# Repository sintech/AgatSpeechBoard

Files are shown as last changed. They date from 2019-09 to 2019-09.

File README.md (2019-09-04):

# Agat Speech Board

КР1803ВЖ1 (TMS5100) based speech synthesizer board for [Agat](https://en.wikipedia.org/wiki/Agat_(computer)) computer.

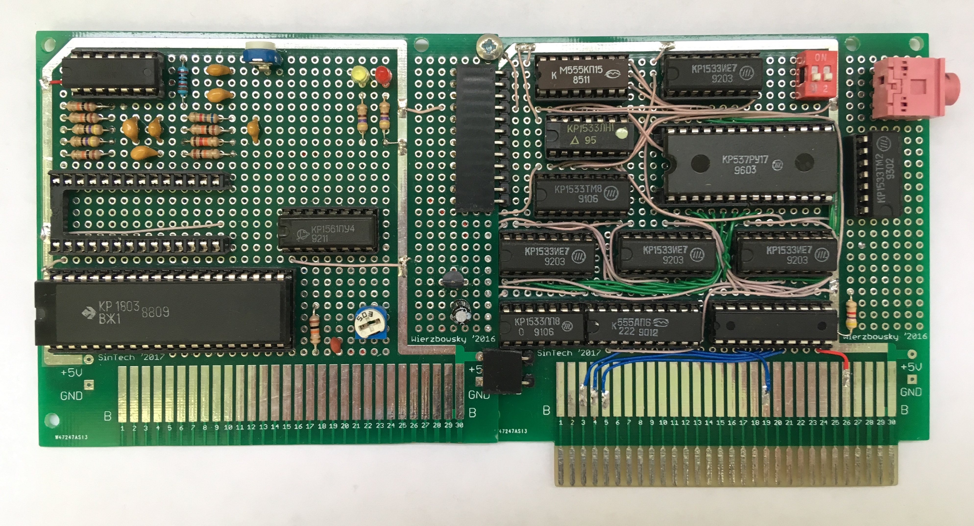
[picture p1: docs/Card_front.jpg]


Schematics was designed in KiCad EDA with a custom parts lib.
Software was created using [cc65](https://cc65.github.io/) compiler. And it works on Agat only in Apple II compatibility mode.

## Project files
- Schematics in KiCad format: [schematics/AgatSpeechBoard](schematics/AgatSpeechBoard), PNG: [Control](schematics/AgatSpeechBoard/AgatSpeechBoard_sch.png), [Analog](schematics/AgatSpeechBoard/AgatSpeechBoard_analog_sch.png)
- ATF16v8 PLD firmware: [PLD Firmware](src/ATF16V8)
- Speak program sources for Agat-9 Apple II mode: [src/speak](src/speak)
- Various datasheets for КР1803ВЖ1 and TMS5100 chips: [docs](docs)
- "Talking Dice" circuit based on TMS5100 chip: [docs/Talking Dice](docs/Talking%20Dice)

## [Chaos Constructions 2019](http://c-c.ru) public report
- Presentation (in Russian): [Синтезатор речи для ПЭВМ Агат.pdf](docs/Синтезатор%20речи%20для%20ПЭВМ%20Агат.pdf)
- Full software demo: https://www.youtube.com/watch?v=xI7s3mxBhng
- Russian phrases: https://www.youtube.com/watch?v=0sAlXTVFXQc
- Speak and Spell emulator: https://www.youtube.com/watch?v=E4hqrfArUSM

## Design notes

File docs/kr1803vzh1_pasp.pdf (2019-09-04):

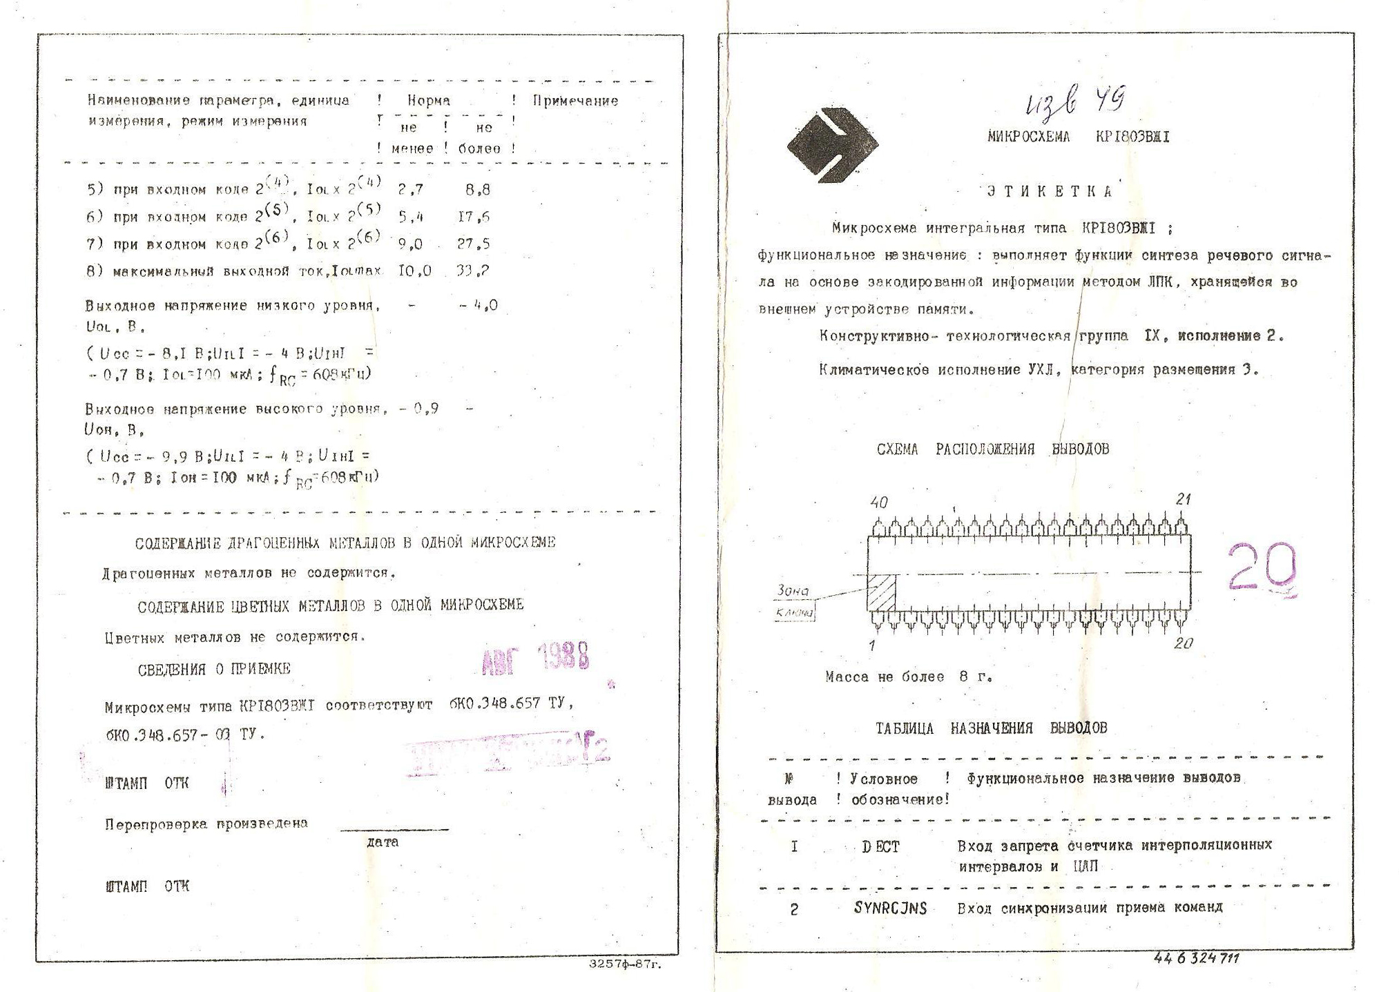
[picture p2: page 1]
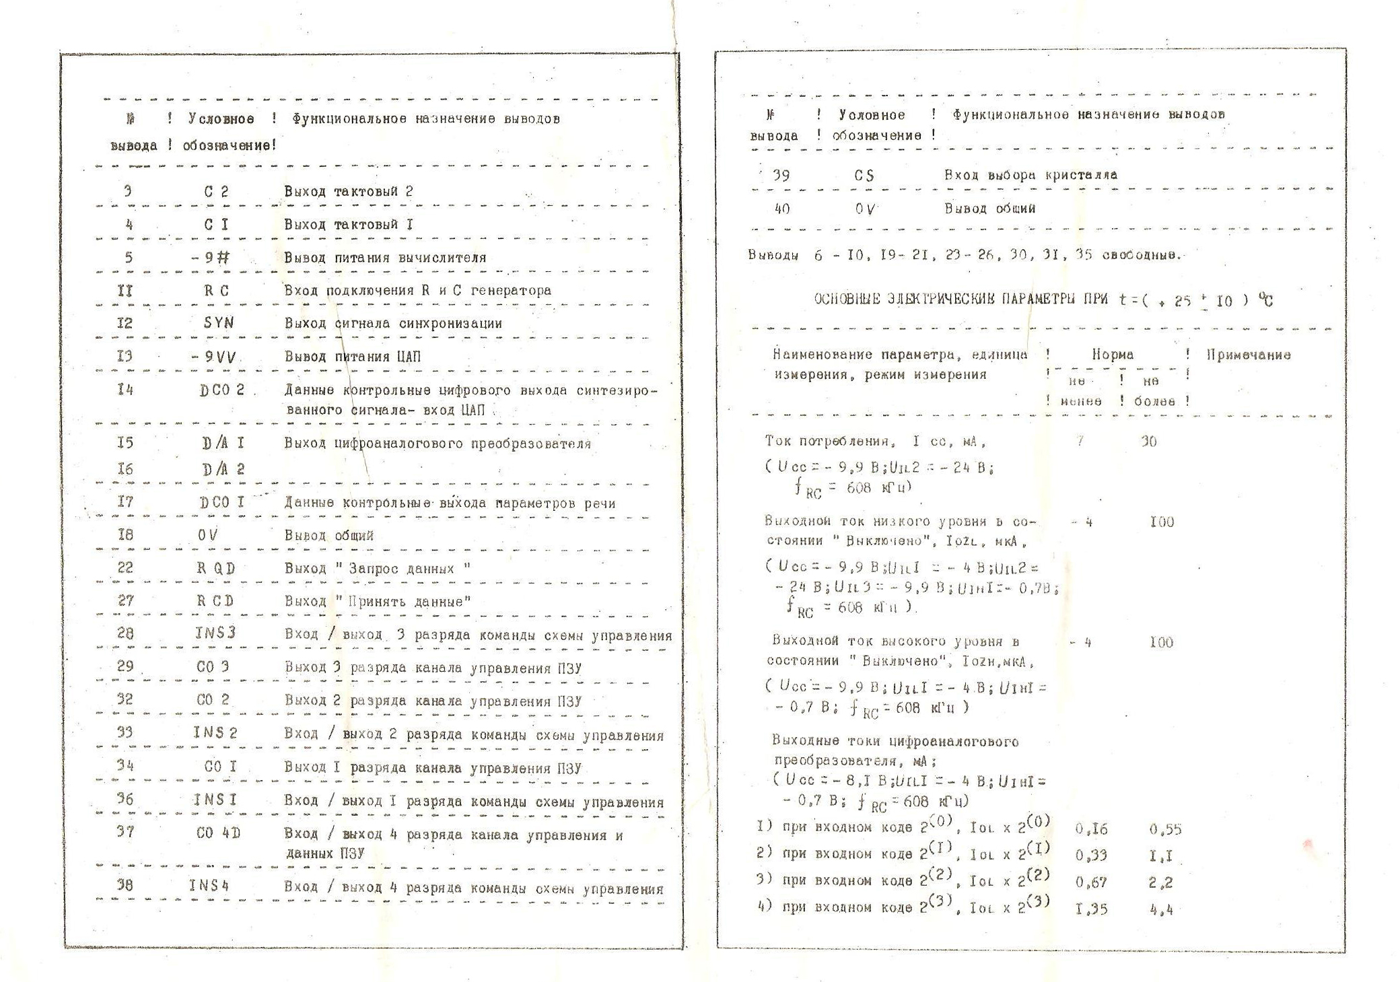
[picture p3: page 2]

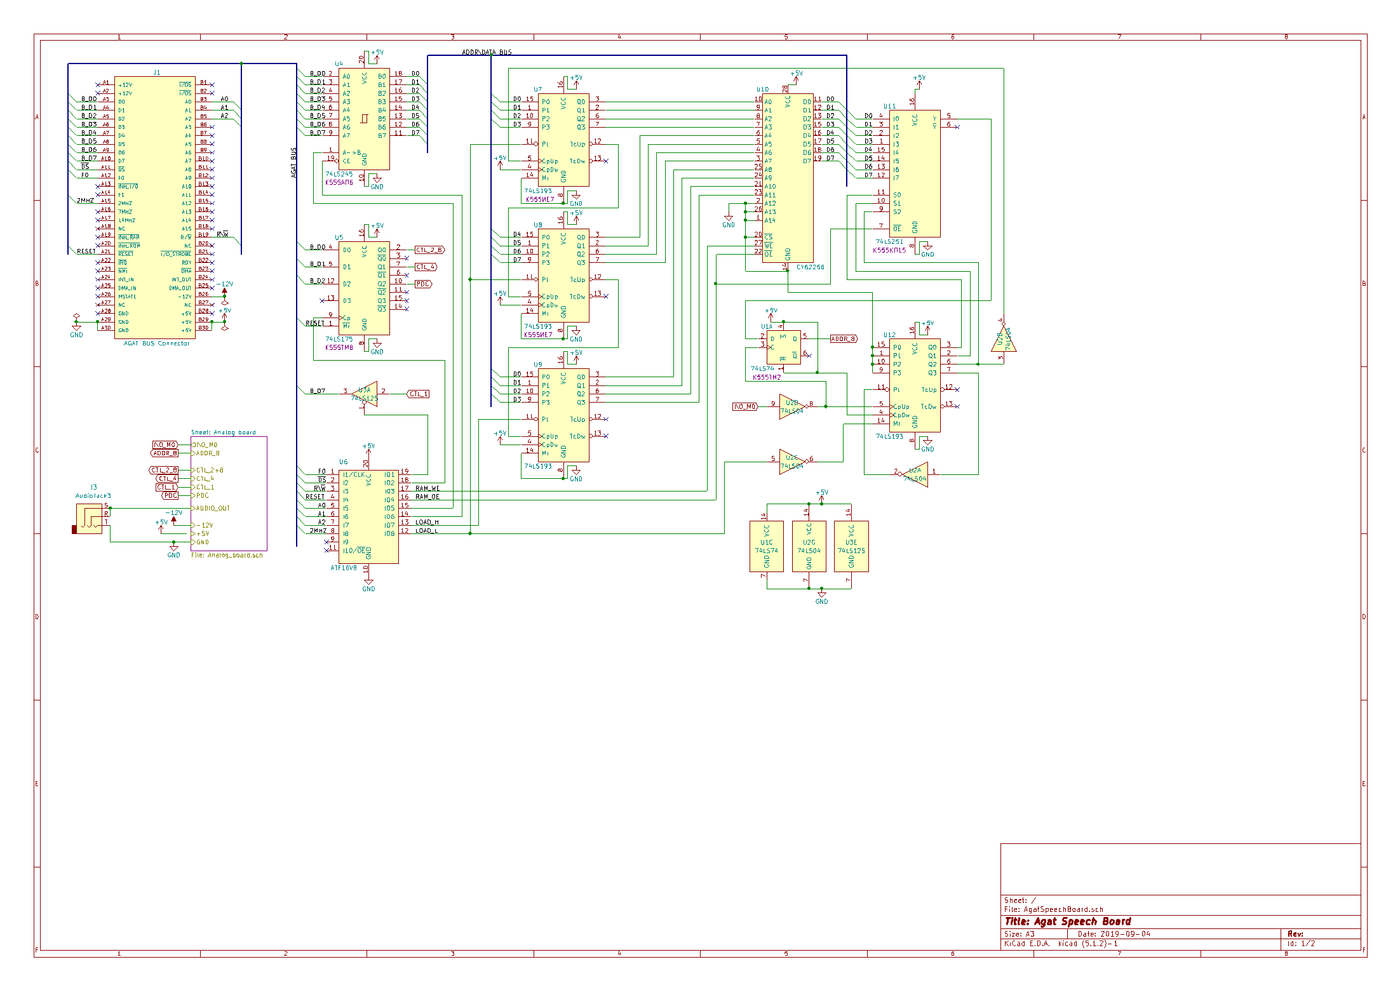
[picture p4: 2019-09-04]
schematics/AgatSpeechBoard/AgatSpeechBoard_sch.png

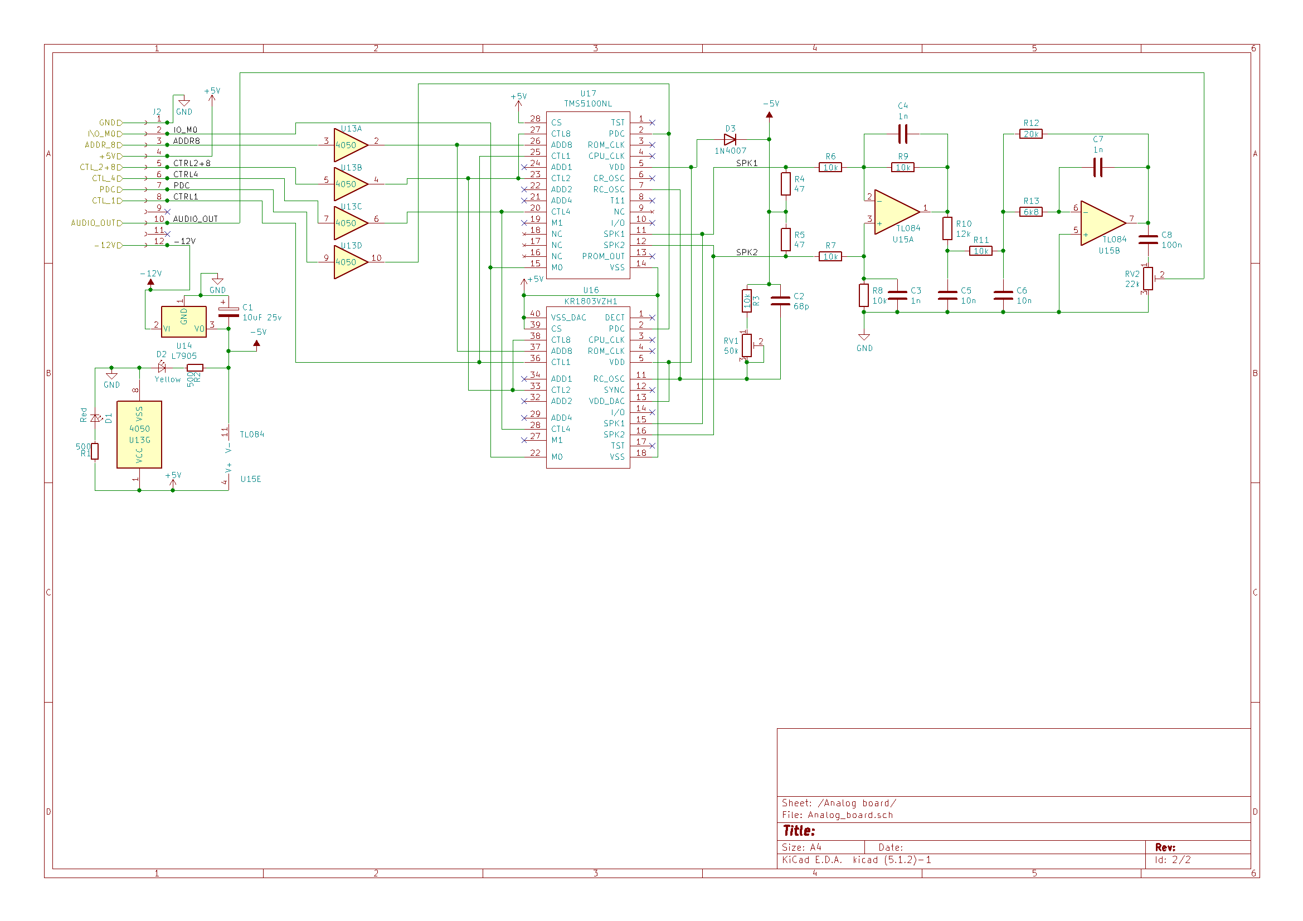
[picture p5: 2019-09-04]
schematics/AgatSpeechBoard/AgatSpeechBoard_analog_sch.png

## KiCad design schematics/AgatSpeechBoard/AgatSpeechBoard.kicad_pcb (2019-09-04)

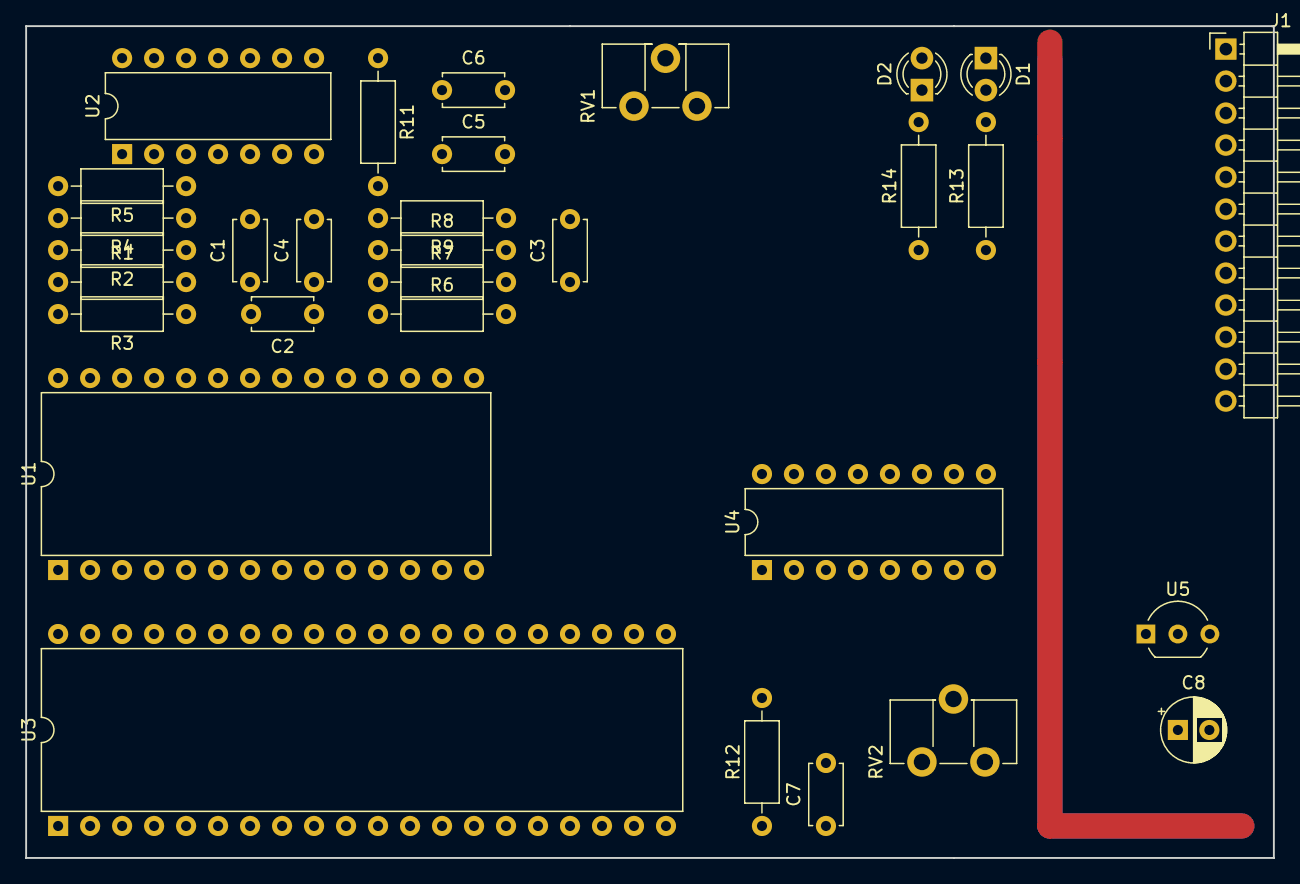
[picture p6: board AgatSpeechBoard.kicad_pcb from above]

Board: 2 copper layers, 99.1 x 66.0 mm, 31 parts (0 on the bottom side), 29 nets.

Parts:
C1, C2, C5: 1n; C_Disc_D4.7mm_W2.5mm_P5.00mm
C3, C4: 10n; C_Disc_D4.7mm_W2.5mm_P5.00mm
C6: 100n; C_Disc_D4.7mm_W2.5mm_P5.00mm
C7: 68p; C_Disc_D4.7mm_W2.5mm_P5.00mm
C8: 10uF 25v; CP_Radial_D5.0mm_P2.50mm
D1: Red; LED_D3.0mm
D2: Yellow; LED_D3.0mm
J1: Conn_01x12_Female; PinHeader_1x12_P2.54mm_Horizontal
R1, R2: 47; R_Axial_DIN0207_L6.3mm_D2.5mm_P10.16mm_Horizontal
R3, R4, R5, R6, R8, R12: 10k; R_Axial_DIN0207_L6.3mm_D2.5mm_P10.16mm_Horizontal
R7: 12k; R_Axial_DIN0207_L6.3mm_D2.5mm_P10.16mm_Horizontal
R9: 6k8; R_Axial_DIN0207_L6.3mm_D2.5mm_P10.16mm_Horizontal
R11: 20k; R_Axial_DIN0207_L6.3mm_D2.5mm_P10.16mm_Horizontal
R13, R14: 500; R_Axial_DIN0207_L6.3mm_D2.5mm_P10.16mm_Horizontal
RV1: 22k; Potentiometer_ACP_CA9-H3,8_Horizontal
RV2: 50k; Potentiometer_ACP_CA9-H5_Horizontal
U1: TMS5100NL; DIP-28_W15.24mm
U2: TL084; DIP-14_W7.62mm
U3: KR1803VZH1; DIP-40_W15.24mm
U4: 4050; DIP-16_W7.62mm
U5: L7905; TO-92_Inline_Wide

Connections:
+5V: J1.4, R13.1, U1.14, U2.4, U3.18, U3.40, U4.1
-5V: C7.1, C8.2, R1.2, R2.1, R12.1, R14.1, U1.5, U2.11, U3.5, U3.13, U5.3
/-12v: J1.12, U5.2
/ADDR8: J1.3, U4.3
/Audio_OUT: J1.10, RV1.2
/CTRL1: J1.8, U1.25, U3.36
/CTRL2+8: J1.5, U4.5
/CTRL4: J1.6, U4.7
/IO_M0: J1.2, U1.15, U3.22
/PDC: J1.7, U4.9
/SPK1: R1.1, R3.2, U1.11, U3.15
/SPK2: R2.2, R4.2, U1.12, U3.16
GND: C1.2, C3.2, C4.2, C8.1, D1.1, D2.2, J1.1, R5.2, RV1.3, U2.5, U4.8, U5.1
unnamed: C1.1, R4.1, R5.1, U2.3
unnamed: C2.1, R6.1, R7.1, U2.1
unnamed: C2.2, R3.1, R6.2, U2.2
unnamed: C3.1, R7.2, R8.2
unnamed: C4.1, R8.1, R9.2, R11.2
unnamed: C5.1, C6.1, R11.1, U2.7
unnamed: C5.2, R9.1, U2.6
unnamed: C6.2, RV1.1
unnamed: C7.2, RV2.2, RV2.3, U1.7, U3.11
unnamed: D1.2, R13.2
unnamed: D2.1, R14.2
unnamed: R12.2, RV2.1
unnamed: U1.2, U3.2, U4.10
unnamed: U1.20, U3.28, U4.6
unnamed: U1.23, U1.27, U3.33, U3.38, U4.4
unnamed: U1.26, U3.37, U4.2
